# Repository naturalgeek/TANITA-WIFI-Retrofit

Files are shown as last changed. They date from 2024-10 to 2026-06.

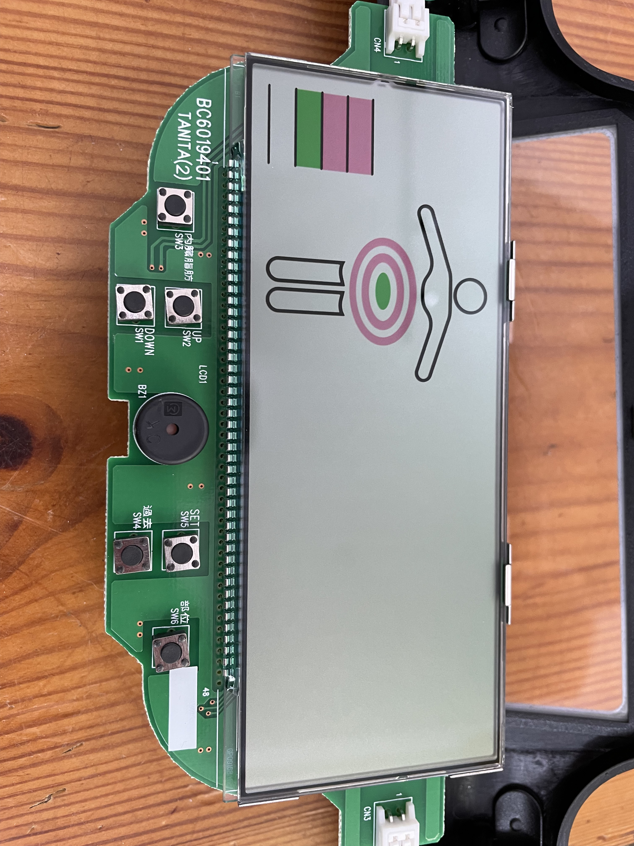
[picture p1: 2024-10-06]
photos/tanita_601_handset_pcb_bottom.jpeg

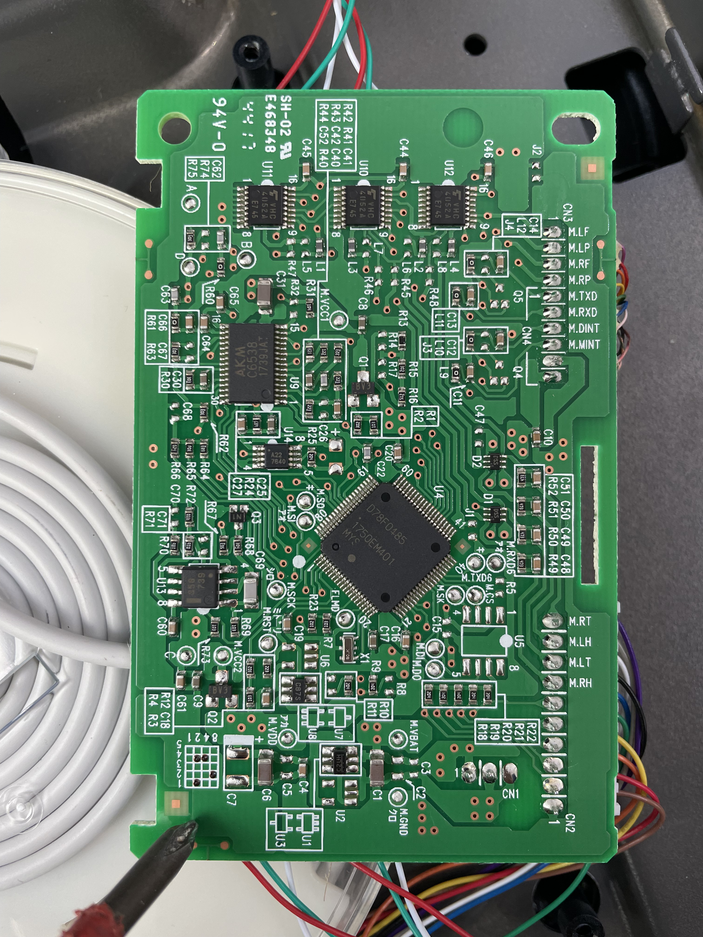
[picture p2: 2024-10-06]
photos/tanita_601_base_pcb_top.jpeg

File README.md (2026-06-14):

# TANITA-WIFI-Retrofit
I'am aiming to build a retrofit PCB to add Wifi to the Tanita 601,603 and 613 Body Scales.

# Current status
In development

# Hot it might work
basically there is a microcontroller in the handset of the scale. This microcontroller communicates to another microcontroller on a separate PCB containting the SD Cardslot via SPI. This is not SPI-SD, the communication happens in a properitary format. This SD-Card PCB can probably be replaced by something like a ESP32 which handles the communication to the mainboard and sends data to some HTTPS endpoint instead of writing it to a memory card.

# Protocol grabber

To document the proprietary protocol from real traffic (instead of guessing),
this repo includes a **passive SPI bus grabber**: an ESP32-S3 high-impedance tap
that listens to the handset ↔ SD-PCB bus while the original SD PCB stays
connected, plus a host decoder that reconstructs files and verifies checksums.

| Piece | Path |
|---|---|
| Passive sniffer firmware (ESP32-S3, dual SPI slave) | [`firmware/tanita_spi_sniffer/`](firmware/tanita_spi_sniffer/) |
| Capture decoder / protocol-doc generator | [`tools/decode_capture.py`](tools/decode_capture.py) |
| Tap schematic (KiCad 8) + wiring | [`hardware/`](hardware/) |
| Step-by-step capture workflow | [`docs/CAPTURE_WORKFLOW.md`](docs/CAPTURE_WORKFLOW.md) |
| Curated protocol spec | [`docs/PROTOCOL.md`](docs/PROTOCOL.md) |
| Auto-generated observed protocol | [`docs/PROTOCOL_OBSERVED.md`](docs/PROTOCOL_OBSERVED.md) |

Quick check that the decoder is sound (runs against the bundled capture):

```bash
python3 tools/decode_capture.py --selftest
```

> Note: the existing `firmware/tanita_spi_capture/` sketch is an **emulator**
> (it impersonates the SD card and fabricates replies) — useful for *replacing*
> the card, but the **grabber** above is the tool for *documenting* the protocol.

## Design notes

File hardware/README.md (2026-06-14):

# Hardware — Passive SPI Protocol Grabber

A high-impedance tap that lets an **ESP32-S3** listen to the SPI bus between the
TANITA handset and the original SD-Card PCB **without disturbing it**. The SD
PCB stays plugged in and the scale keeps working normally; the ESP32 only
listens and streams what it sees over USB.

## Signal map (from the SD-PCB silkscreen)

The bridge MCU on the SD PCB uses TI-style SPI names. Connector **CN1** carries
the handset link:

| CN1 signal | Meaning | = standard SPI | Direction |
|---|---|---|---|
| `SCK`  | serial clock | SCLK | handset → SD (master drives) |
| `CS` | chip select, active low | CS  | handset → SD |
| `SIMO` | Slave-In-Master-Out | **MOSI** | handset → SD |
| `SOMI` | Slave-Out-Master-In | **MISO** | SD → handset |
| `GND`  | ground | GND  | — |
| `VCC`  | ~3.3 V rail | — | **do not tap** |

> The MCU has a *second* SPI bus to the on-board SD card (silkscreen `S.SIMO`,
> `S.SOMI`, `S.SCK`). We tap **CN1 (the handset side)**, not the card side.

⚠️ **The exact wire-colour → pin order on CN1 must be confirmed on your unit**
before trusting it — see "Identify the wires" below. The grabber self-verifies
once running (it will only see valid framed traffic when SCK/CS are correct).

## Connections

| TANITA CN1 | via | ESP32-S3 GPIO | Role |
|---|-----|---|---|
| `SCK`  | R1 100 Ω | **GPIO12** | shared SPI clock (both peripherals) |
| `CS` | R2 100 Ω | **GPIO10** | shared chip select (active low) |
| `SIMO` | R3 100 Ω | **GPIO11** | MOSI → SPI2 listens here |
| `SOMI` | R4 100 Ω | **GPIO13** | MISO → SPI3 listens here |
| `GND`  | — | **GND** | **required** common ground |
| `VCC`  | — | *(leave unconnected)* | power ESP32 from USB instead |

`R1–R4` are optional ~100 Ω in-line series resistors (protection / impedance
isolation). 0 Ω / plain wire works too because the ESP32 pins are pure inputs
(`miso_io_num = -1`, so nothing is ever driven back onto the bus).

## ASCII schematic

```
 TANITA handset  <-------- ribbon -------->  SD-Card PCB (stays connected)
                         CN1 (tap here)
                         |
   CN1.SCK  o---[R1 100]---+----------------> ESP32-S3 GPIO12   (SCK,  shared)
   CN1.CS   o---[R2 100]---+----------------> ESP32-S3 GPIO10   (CS_n, shared)
   CN1.SIMO o---[R3 100]---+----------------> ESP32-S3 GPIO11   (MOSI -> SPI2)
   CN1.SOMI o---[R4 100]---+----------------> ESP32-S3 GPIO13   (MISO -> SPI3)
   CN1.GND  o-------------------------------- ESP32-S3 GND      (common)
   CN1.VCC  x  (DO NOT CONNECT)               ESP32-S3 5V <- USB
```

The two ESP32 SPI peripherals share SCK + CS and each watch one data line, so a
single CS pulse yields a byte-aligned MOSI/MISO pair. Neither peripheral drives
a pin, so the tap is invisible to the live bus.

## Breadboard wiring drawing

Physical layout (which board, which jumper) — Fritzing-breadboard style:

Breadboard wiring

Regenerate with `python3 hardware/gen_breadboard_svg.py`. Wire colours in the
drawing are **illustrative** — confirm the real CN1 wire/pin order on your unit
(see "Identify the wires" below).

## Bill of materials

| Ref | Part | Notes |
|-----|---|---|
| U1 | ESP32-S3 DevKitC (or any dual-SPI ESP32-S3) | needs SPI2 **and** SPI3 free |
| J1 | wires/clip to CN1 (JST-PH 7-pin on the SD PCB) | tap in parallel |
| R1–R4 | 100 Ω 0603/through-hole | optional but recommended |

## Schematic files

- `tanita_sniffer.kicad_sch` — KiCad 8 schematic (open with `tanita_sniffer.kicad_pro`).
- `gen_schematic.py` — regenerates the `.kicad_sch`; the netlist lives in code,
  so edit pins/nets there and re-run `python3 hardware/gen_schematic.py`.

Targets KiCad 8 (file format `20231120`). If your KiCad version refuses to open
it, the wiring tables above are the authoritative netlist.

## Identify the wires (do this first)

A dual-slave sniffer must know which CN1 wire is **SCK** and which is **CS** to
frame transactions. To confirm on your unit:

1. **GND / VCC** — power off, multimeter continuity: GND rings to the SD-card
   shield and bypass-cap ground; VCC to the cap positive.
2. **SCK** — power on, scope/logic-analyzer: a steady burst clock during a
   measurement save or on power-up.
3. **CS** — idles high, pulses low around each clock burst.
4. **SIMO vs SOMI** — capture both data lines; the one carrying the known
   command `04 12 00 E9` (handset→SD ping) is **SIMO/MOSI**; the line replying
   `04 92 00 69` is **SOMI/MISO**. If reversed, swap GPIO11/GPIO13.

A cheap 8-channel logic analyzer + `sigrok`/PulseView on all six wires for one
measurement cycle is the fastest way to lock this down before soldering.

## Safety

- TANITA logic is **3.3 V** — never feed 5 V into these pins.
- **Common the grounds.** No shared GND = garbage capture and possible damage.
- Do **not** tap VCC; powering the ESP32 from USB while also backfeeding the
  handset rail can fight the scale's regulator.

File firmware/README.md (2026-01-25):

# TANITA WiFi Retrofit - ESP32 Firmware

This firmware allows an ESP32 to replace the SD Card PCB in TANITA BC-601/603/613 body scales, enabling wireless transmission of measurement data.

## Hardware Requirements

- ESP32 development board (ESP32-WROOM-32 recommended)
- Level shifter if your ESP32 is 5V logic (the TANITA uses 3.3V)
- Connecting wires

## Wiring

Connect the ESP32 to the TANITA handset connector (the cable that normally goes to the SD Card PCB):

| TANITA Signal | ESP32 GPIO | Function |
|---|---|---|
| MOSI | GPIO23 | Data from handset to ESP32 |
| MISO | GPIO19 | Data from ESP32 to handset |
| SCLK | GPIO18 | SPI clock (from handset) |
| CS | GPIO5 | Chip select (active low) |
| VCC | 3.3V | Power |
| GND | GND | Ground |

**Important:** The TANITA handset is the SPI master; the ESP32 runs as an SPI slave.

## Sketches

### 1. tanita_spi_capture (Start here!)

Simple debug sketch for testing your wiring and capturing protocol data. This sketch:
- Captures all SPI transactions
- Logs everything to Serial (115200 baud)
- Responds to the TANITA protocol
- Displays captured measurement data

**Use this first** to verify your hardware connection works!

### 2. tanita_wifi

Full implementation with WiFi transmission. Features:
- Complete protocol implementation
- WiFi connectivity
- HTTPS POST of measurement data as JSON
- Measurement data parsing

## Building

### Using PlatformIO (Recommended)

```bash
cd firmware

# Build capture sketch
pio run -d tanita_spi_capture

# Upload capture sketch
pio run -d tanita_spi_capture --target upload

# Monitor serial output
pio device monitor -b 115200

# For the WiFi version:
pio run -d tanita_wifi
pio run -d tanita_wifi --target upload
```

### Using Arduino IDE

1. Install ESP32 board support
2. Open the `.ino` file
3. Select "ESP32 Dev Module" as board
4. Upload

## Configuration

Edit `tanita_wifi/config.h`:

```cpp
// WiFi settings
#define WIFI_SSID         "YOUR_WIFI_SSID"
#define WIFI_PASSWORD     "YOUR_WIFI_PASSWORD"

// API endpoint
#define API_ENDPOINT      "https://your-server.com/api/weight"
#define API_KEY           "your-api-key-here"

// Pin mapping (if different from defaults)
#define PIN_SPI_MOSI      23
#define PIN_SPI_MISO      19
#define PIN_SPI_SCLK      18
#define PIN_SPI_CS        5
```

## Protocol Overview

The TANITA uses a proprietary SPI protocol (NOT standard SD card SPI):

### Frame Format
```
[length] [command] [payload...] [checksum]
```

- `length`: Total frame length in bytes
- `command`: Operation code
- `payload`: Variable length data
- `checksum`: `~(sum of all other bytes) & 0xFF`

### Key Commands

| Cmd | Description |
|-----|---|
| 0x11, 0x12, 0x13 | Status/handshake |
| 0x14 | File operation init |
| 0x21 | Read file path |
| 0x22 | End transfer |
| 0x23 | Request data chunk |
| 0x24 | Write data chunk |
| 0x27 | Allocate space |
| 0x41 | Write file path |

Responses have bit 7 set: `response = command | 0x80`

### Measurement Data Format

Data is CSV with key-value pairs:
```
MO,"BC-601",DT,"01/01/2024",Ti,"08:30:00",Wk,65.5,FW,18.2,...
```

Key fields:
- `Wk`: Weight (kg)
- `FW`: Body fat (%)
- `mW`: Muscle mass (kg)
- `bW`: Bone mass (kg)
- `ww`: Body water (%)
- `rD`: BMR (kcal)
- `rA`: Metabolic age

## SPI Slave Considerations

The ESP32 runs as an SPI slave, which has timing challenges:

1. **Response Timing**: The response must be ready in the TX buffer before the master starts the next transaction
2. **Full Duplex**: SPI is simultaneous bidirectional - the first response may contain garbage
3. **DMA Required**: Use DMA for reliable data transfer

The handset appears to use separate transactions for command and response, giving us time to prepare responses.

## Troubleshooting

### No data received
- Check wiring (especially MOSI, SCLK, CS)
- Verify 3.3V power
- Check that CS pin is correctly connected

### Garbled data
- Try different SPI modes (currently using Mode 0)
- Check clock polarity with oscilloscope/logic analyzer
- Verify ground connection

### Scale shows error
- The response timing may be off
- Check checksum calculations
- Verify file content responses

### WiFi connection fails
- Check SSID and password in config.h
- Ensure router is 2.4GHz (ESP32 doesn't support 5GHz)

## Data Flow

```
[TANITA Scale] --weighs--> [Handset MCU]
                               |
                          SPI (proprietary)
                               |
                               v
                          [ESP32 Slave]
                               |
                           WiFi/HTTPS
                               |
                               v
                        [Your Server]
```

## JSON Output Format

The WiFi sketch sends data as JSON:
```json
{
  "model": "BC-601",
  "date": "01/01/2024",
  "time": "08:30:00",
  "weight": 65.5,
  "bodyFat": 18.2,
  "muscleMass": 51.5,
  "boneMass": 2.7,
  "bodyWater": 55.3,
  "bmr": 1650,
  "metabolicAge": 28,
  "physiqueRating": 5,
  "fatSegments": {
    "rightArm": 15.2,
    "leftArm": 14.8,
    "rightLeg": 18.5,
    "leftLeg": 18.2,
    "trunk": 16.8
  },
  "muscleSegments": {
    "rightArm": 3.1,
    "leftArm": 3.0,
    "rightLeg": 9.5,
    "leftLeg": 9.3,
    "trunk": 27.5
  }
}
```

## License

MIT License - See repository root for details.

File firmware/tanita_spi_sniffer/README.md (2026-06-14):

# tanita_spi_sniffer — passive SPI grabber (ESP32-S3)

Passively taps the handset ↔ SD-PCB SPI bus and streams every CS-framed
transaction over USB serial. **Listens only** — both ESP32 SPI peripherals run
as slaves with `miso_io_num = -1`, so nothing is ever driven onto the live bus.
The original SD PCB stays connected and the scale keeps working.

This is the tool to use for **documenting** the protocol. (The sibling
`tanita_spi_capture` sketch is an *emulator* that pretends to be the SD card and
fabricates replies — useful for replacement, wrong for reverse-engineering.)

## How it works

Each logical message in the TANITA protocol is its own CS pulse and is
meaningful in only one direction. To capture full duplex we run **two** SPI
slaves on the **same** SCK and CS:

| Peripheral | Listens on | Captures |
|---|---|---|
| SPI2 | `SIMO`/MOSI (GPIO11) | handset → SD |
| SPI3 | `SOMI`/MISO (GPIO13) | SD → handset |

A CS pulse ends both transactions at once, giving a byte-aligned MOSI/MISO pair.
The host decoder picks the active direction per pulse by checksum.

Pins are defined at the top of `tanita_spi_sniffer.ino` (defaults match
`hardware/README.md`). SPI mode 0 is assumed — confirm CPOL/CPHA with a scope if
you see garbage.

## Build / flash / capture

```bash
cd firmware
pio run -e sniffer -t upload          # build + flash the ESP32-S3
pio device monitor -e sniffer | tee capture.txt   # record at 921600 baud
```

Trigger traffic on the scale: power-on reads `SYSTEM.TXT` + profiles; completing
a measurement writes `DATAn.CSV`. Capture a full power-on **and** a weigh-in.

## Output format

One line per CS transaction (`#` lines are metadata):

```
<seq>\t<t_us>\t<MOSI hex bytes>\t|\t<SOMI hex bytes>
```

Example (idle line shows as 00s; decoder keeps the framed side):

```
0   1240   04 12 00 E9    |   00 00 00 00
1   1530   00 00 00 00    |   04 92 00 69
```

## Decode

```bash
python3 ../tools/decode_capture.py capture.txt              # annotated log + files
python3 ../tools/decode_capture.py capture.txt --md ../docs/PROTOCOL_OBSERVED.md
```

See `docs/CAPTURE_WORKFLOW.md` for the full procedure.

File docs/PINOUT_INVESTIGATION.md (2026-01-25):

# Connector Pinout Investigation Guide

## The Connector

Based on the photos, the SD Card PCB has a 6-7 pin connector with colored wires going to the handset. You'll need to identify which wire corresponds to which SPI signal.

## Expected Signals

For SPI communication, we need:
| Signal | Description |
|---|---|
| VCC | 3.3V Power (likely red or orange wire) |
| GND | Ground |
| MOSI | Master Out Slave In (data TO the SD PCB) |
| MISO | Master In Slave Out (data FROM the SD PCB) |
| SCLK | SPI Clock |
| CS | Chip Select (active low) |

## Investigation Methods

### Method 1: Visual Inspection

From the PCB top photo, I can see "VCC" labeled near the connector. Trace other signals by following PCB traces to:
- The main microcontroller
- The SD card slot pins (standard SD card pinout is documented)

### Method 2: Multimeter Continuity Test

With the board powered OFF:
1. Set multimeter to continuity mode
2. Find GND by testing for continuity to the SD card slot's GND pins
3. Find VCC by testing for continuity to bypass capacitors' positive side
4. SPI signals will go to the microcontroller

### Method 3: Logic Analyzer / Oscilloscope

With the board connected to the handset (powered on):
1. Connect logic analyzer probes to each wire
2. Trigger a measurement on the scale
3. Identify signals by their characteristics:
   - **SCLK**: Regular clock pulses
   - **MOSI**: Data changing on clock edges (commands from handset)
   - **MISO**: Data changing on clock edges (responses from SD PCB)
   - **CS**: Goes low during transactions

### Method 4: Compare with SD Card Pinout

Standard SD card SPI pinout (looking at card from front, contacts up):
```
Pin 1: CS (Chip Select)
Pin 2: MOSI (Data In)
Pin 3: GND
Pin 4: VCC (3.3V)
Pin 5: SCLK (Clock)
Pin 6: GND
Pin 7: MISO (Data Out)
```

However, remember the TANITA uses a **proprietary protocol**, not standard SD SPI. The microcontroller on the SD PCB translates between the proprietary protocol and actual SD card access.

## Wire Color Observations

From the photos, the visible wire colors are approximately:
- Red/Orange
- Yellow
- Green
- Blue
- Purple/Pink
- (possibly more)

Common conventions (may not apply):
- Red = VCC
- Black = GND
- Other colors = signals

## Recommended Approach

1. **Identify VCC and GND first** using multimeter
2. **Use logic analyzer** to capture actual SPI communication
3. Compare captured data with the protocol documentation
4. Once you identify MOSI (data from handset), you should see the known command sequences

## Safety Notes

- The TANITA operates at 3.3V - do NOT connect 5V signals
- Always verify power connections before connecting your ESP32
- Start with the capture sketch to verify wiring before using the full firmware

## ESP32 Default Pin Mapping

Once you identify the signals, connect them to these ESP32 pins:

| Signal | ESP32 GPIO | Notes |
|---|---|---|
| VCC | 3.3V pin | Power from TANITA or external |
| GND | GND | Common ground |
| MOSI | GPIO23 | Can be changed in config.h |
| MISO | GPIO19 | Can be changed in config.h |
| SCLK | GPIO18 | Can be changed in config.h |
| CS | GPIO5 | Can be changed in config.h |

## Example Logic Analyzer Capture

When you capture SPI data, you should see patterns like:

**Ping-Pong Handshake:**
```
MOSI: 04 12 00 E9
MISO: 04 92 00 69
```

**File Path Request:**
```
MOSI: 23 21 54 41 4E 49 54 41 2F ...  (TANITA/...)
```

If your MOSI/MISO are swapped, swap your connections!

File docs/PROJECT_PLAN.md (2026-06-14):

# TANITA WiFi Retrofit - Project Plan

## Project Overview

**Goal:** Replace the SD Card PCB in TANITA BC-601/603/613 body scales with an ESP32 to send weight/body composition data via WiFi instead of storing to SD card.

**Repository:** https://github.com/naturalgeek/TANITA-WIFI-Retrofit

**Two tools, two jobs** (don't confuse them):
- **Grabber** (`firmware/tanita_spi_sniffer`) — passively taps the live bus to *document* the protocol from real traffic. The original SD PCB stays connected.
- **Emulator** (`firmware/tanita_spi_capture`, `firmware/tanita_wifi`) — *impersonates* the SD card and answers the handset. This is what eventually *replaces* the card and adds WiFi.

---

## Current Status (June 2026)

### Completed ✅

| Task | Status | Notes |
|---|---|---|
| Protocol reverse engineering | ✅ Done | SPI captures analyzed, frame format decoded |
| Protocol documentation | ✅ Done | `docs/PROTOCOL.md` — curated reference |
| Checksum algorithm | ✅ **Verified** | `~(sum of bytes) & 0xFF`; decoder self-test = 0 failures across 78 real frames |
| Command/response mapping | ✅ Done | All observed commands documented |
| Data format parsing | ✅ Done | CSV key-value format understood |
| **Passive SPI grabber firmware** | ✅ Done | `firmware/tanita_spi_sniffer/` — ESP32-S3 dual-SPI-slave, listens only |
| **Capture decoder / doc generator** | ✅ Done | `tools/decode_capture.py` — validates checksums, reconstructs files, emits `PROTOCOL_OBSERVED.md`; ships `--selftest` |
| **Observed-protocol doc (auto-gen)** | ✅ Done | `docs/PROTOCOL_OBSERVED.md` generated from the bundled capture |
| **Capture workflow** | ✅ Done | `docs/CAPTURE_WORKFLOW.md` — tap → flash → capture → decode |
| **KiCad schematic (tap)** | ✅ Done | `hardware/tanita_sniffer.kicad_sch` (+ generator) |
| **Breadboard wiring drawing** | ✅ Done | `hardware/tanita_sniffer_breadboard.svg` (+ generator) |
| Signal naming confirmed (silkscreen) | ✅ Done | `SIMO`=MOSI, `SOMI`=MISO, `SCK`, `CS`, `GND`, `VCC`; 2nd (SD-side) bus identified |
| ESP32 firmware (emulator) | ✅ Done | `firmware/tanita_spi_capture/` |
| ESP32 firmware (WiFi) | ✅ Done | `firmware/tanita_wifi/` |
| Wiring guide | ✅ Done | `docs/WIRING_GUIDE.md` with ASCII diagrams |
| Pinout investigation guide | ✅ Done | `docs/PINOUT_INVESTIGATION.md` |
| PlatformIO config | ✅ Done | `firmware/platformio.ini` — per-env source filters (`sniffer`/`capture`/`wifi`) |

### In Progress / Pending hardware 🔄

| Task | Status | Blocker |
|---|---|---|
| Confirm exact CN1 wire→pin order | 🔄 Pending | Multimeter + logic analyzer on the physical unit |
| Compile-test all firmware | 🔄 Pending | No ESP toolchain in the dev env yet (`pio run`) |
| Open KiCad schematic in KiCad | 🔄 Pending | Targets format `20231120` (KiCad 8); not yet opened |
| Run the grabber on real hardware | 🔄 Pending | Requires wired tap + a measurement cycle |
| Real-world testing | 🔄 Pending | Requires hardware setup |

### Not Started ⏳

| Task | Priority | Complexity |
|---|---|---|
| Verify SPI mode (CPOL/CPHA) on scope | High | Low |
| Capture real power-on + weigh-in with grabber | High | Low |
| Reconcile `PROTOCOL.md` vs captured `PROTOCOL_OBSERVED.md` | High | Low |
| Validate emulator against the live scale | High | Medium |
| WiFi endpoint integration | Medium | Low |
| Power consumption optimization | Low | Medium |
| Custom PCB design | Low | High |
| 3D printed enclosure | Low | Medium |

---

## Milestones

### Milestone 1: Bench bring-up & wire identification 🎯
**Target:** Know exactly which CN1 wire is which, and the bus's electrical params.

- [ ] Identify GND/VCC with multimeter; SCK/CS/SIMO/SOMI with logic analyzer
- [ ] Document wire-colour → signal mapping for your unit
- [ ] Measure clock frequency and confirm 3.3 V levels
- [ ] Confirm SPI mode (CPOL/CPHA) on a scope

### Milestone 2: Passive protocol grab & documentation 🎯  *(recommended first — non-invasive)*
**Target:** Ground-truth protocol docs generated from real traffic, SD PCB untouched.

- [ ] `pio run -e sniffer -t upload` (compile-test first)
- [ ] Wire the high-impedance tap (see `hardware/` schematic + breadboard SVG)
- [ ] Capture a full **power-on** (reads SYSTEM.TXT, PROF*.CSV)
- [ ] Capture a full **weigh-in** (writes DATA*.CSV)
- [ ] `decode_capture.py capture.txt --md docs/PROTOCOL_OBSERVED.md` → 0 checksum failures
- [ ] Reconcile `docs/PROTOCOL.md` with the captured `PROTOCOL_OBSERVED.md` (capture wins)

### Milestone 3: Emulator validation 🎯
**Target:** ESP32 impersonates the SD card; the scale completes a measurement.

- [ ] `pio run -e capture -t upload`
- [ ] Verify ping-pong handshake (0x12/0x92, 0x13/0x93, 0x11/0x91)
- [ ] Verify file-read responses (SYSTEM.TXT, PROF1.CSV)
- [ ] Verify file-write capture (DATA1.CSV)
- [ ] Scale completes measurement without errors

### Milestone 4: WiFi Integration 🎯
**Target:** Measurement data sent to a server.

- [ ] Configure WiFi credentials (`config.h`)
- [ ] Stand up an HTTPS endpoint and verify JSON payload
- [ ] Test data transmission with real measurements
- [ ] Handle connection failures gracefully

### Milestone 5: Production Ready 🎯
**Target:** Reliable, permanent installation.

- [ ] Long-term stability testing
- [ ] Power from TANITA (not USB)
- [ ] Design custom adapter PCB
- [ ] Create 3D printed enclosure
- [ ] Document final installation process

---

## Task Backlog (Linear Import Format)

### Epic: Hardware Setup

```
[HIGH] Identify TANITA connector pinout      [partially done]
- Signal NAMES confirmed from SD-PCB silkscreen (SIMO/SOMI/SCK/CS/GND/VCC)
- Still need: wire-colour -> pin-order mapping on the physical CN1
- Use multimeter (GND/VCC) + logic analyzer (SPI lines)
Labels: hardware, blocking
Estimate: 1h

[HIGH] Wire the passive tap
- Tap SCK/CS/SIMO/SOMI + common GND in parallel with the SD PCB
- Do NOT connect handset VCC; power ESP32 from USB
- See hardware/ schematic + breadboard SVG
Labels: hardware
Estimate: 1h
Depends: Identify connector pinout

[MEDIUM] Verify SPI electrical characteristics
- Measure clock frequency, confirm 3.3V levels, check CPOL/CPHA
Labels: hardware, investigation
Estimate: 1h
```

### Epic: Toolchain / CI

```
[HIGH] Compile-test all three sketches
- pio run -e sniffer / -e capture / -e wifi
- Firmware was authored without a local ESP toolchain; never built yet
Labels: firmware, blocking
Estimate: 1h

[LOW] Open hardware/tanita_sniffer.kicad_sch in KiCad 8
- Confirm it loads + ERC clean; regenerate via gen_schematic.py if needed
Labels: hardware, verification
Estimate: 0.5h
```

### Epic: Protocol Grab & Documentation

```
[HIGH] Capture real traffic with the grabber
- Flash tanita_spi_sniffer, record power-on + a full weigh-in at 921600 baud
- pio device monitor -e sniffer | tee capture.txt
Labels: firmware, protocol, testing
Depends: Wire the passive tap
Estimate: 1h

[HIGH] Decode + regenerate observed protocol doc
- decode_capture.py capture.txt --md docs/PROTOCOL_OBSERVED.md
- Expect 0 checksum failures; reconstructed files match declared sizes
Labels: tooling, protocol
Estimate: 0.5h

[MEDIUM] Reconcile curated vs observed protocol
- Diff PROTOCOL.md against PROTOCOL_OBSERVED.md; capture is source of truth
- Commit the capture under protocol/ as evidence
Labels: documentation, protocol
Estimate: 1h
```

### Epic: Emulator Validation

```
[HIGH] Validate handshake + file read/write against the live scale
- Upload tanita_spi_capture; scale must complete a measurement
- Verify handshake, SYSTEM.TXT/PROF1.CSV reads, DATA1.CSV write
Labels: firmware, protocol, testing
Depends: Capture real traffic with the grabber
Estimate: 3h

[MEDIUM] Handle edge cases
- Multiple profiles (PROF2-4), guest mode, error recovery
Labels: firmware, protocol
Estimate: 3h
```

### Epic: WiFi Integration

```
[MEDIUM] Configure WiFi connection
- Set credentials in config.h, test stability + reconnection
Labels: firmware, wifi
Estimate: 1h

[MEDIUM] Set up test endpoint
- Simple HTTPS server, accept JSON POST, log received data
Labels: backend, testing
Estimate: 2h

[MEDIUM] Test data transmission
- Verify JSON format + all measurement fields with real measurements
Labels: firmware, testing
Estimate: 2h

[LOW] Add data buffering
- Store measurements offline, retry failed sends, SPIFFS persistence
Labels: firmware, enhancement
Estimate: 4h
```

### Epic: Production Hardening

```
[LOW] Optimize power consumption
- Measure current draw, sleep modes, battery impact
Labels: firmware, optimization
Estimate: 4h

[LOW] Design adapter PCB
- Schematic -> layout -> prototype (start from hardware/ KiCad files)
Labels: hardware, pcb
Estimate: 8h

[LOW] Create enclosure
- Measure available space, design 3D model, print + test fit
Labels: hardware, mechanical
Estimate: 4h

[LOW] Write installation guide
- Step-by-step instructions, photos, troubleshooting
Labels: documentation
Estimate: 2h
```

---

## Risk Register

| Risk | Probability | Impact | Mitigation |
|---|---|---|---|
| SPI timing too fast for ESP32 slave | Medium | High | DMA + queued transactions (`QUEUE_DEPTH`); grabber confirms achievable rate |
| Wrong SPI mode → garbage capture | Medium | Medium | Confirm CPOL/CPHA on scope before trusting captures |
| Grabber misses back-to-back transactions | Low | Medium | Raise `QUEUE_DEPTH`; decoder flags checksum gaps |
| Protocol has undocumented commands | Low | Medium | Grabber + decoder surface unknown opcodes; capture more scenarios |
| Firmware untested on hardware (not yet built) | High | Medium | Compile-test, then bench-validate on a real unit |
| TANITA power insufficient for ESP32 | Medium | Medium | Use external/USB power |
| Different TANITA models differ | Low | High | Re-grab per model; protocol is data-driven |

---

## Technical Debt

1. **Firmware never compiled or hardware-tested** — authored without an ESP toolchain; build + bench-validate before trusting.
2. **KiCad schematic not opened in KiCad** — generated to format `20231120`; verify load + ERC.
3. **Breadboard wire colours are illustrative** — real CN1 colour order must be confirmed per unit.
4. **SPI Mode hardcoded** — Mode 0 assumed in both sniffer and emulator; may need configuration.
5. **No persistent storage (WiFi path)** — measurements lost if WiFi fails.
6. **Hardcoded profile data in emulator** — should read from the actual scale config.
7. **No OTA updates** — requires USB for firmware updates.

---

## Resources

- Curated protocol spec: `docs/PROTOCOL.md`
- Auto-generated observed protocol: `docs/PROTOCOL_OBSERVED.md`
- Capture workflow: `docs/CAPTURE_WORKFLOW.md`
- Wiring guide: `docs/WIRING_GUIDE.md`
- Pinout investigation: `docs/PINOUT_INVESTIGATION.md`
- Hardware (schematic + breadboard + BOM): `hardware/`
- Capture decoder: `tools/decode_capture.py` (`--selftest`)
- Firmware READMEs: `firmware/README.md`, `firmware/tanita_spi_sniffer/README.md`
- Hardware photos: `photos/`

---

## Timeline Estimate

| Phase | Duration | Dependencies |
|---|---|---|
| Bench bring-up + wire ID | 0.5-1 day | Logic analyzer, multimeter |
| Passive grab + doc reconciliation | 0.5-1 day | Wired tap, compiled sniffer |
| Emulator validation | 2-3 days | Captured protocol, working hardware |
| WiFi integration | 1 day | Validated emulator |
| Production hardening | 1-2 weeks | Optional |

**Minimum viable prototype:** ~1 week from hardware setup start.

---

_Last updated: 2026-06-14 — reflects the passive grabber + decoder + hardware tooling merged in PR #2._

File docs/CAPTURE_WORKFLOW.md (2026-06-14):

# Capture Workflow — from bus tap to accurate protocol docs

End-to-end recipe for grabbing the TANITA SPI protocol and turning the raw
capture into verified documentation.

```
 ┌────────────┐   ribbon    ┌────────────┐
 │  handset   │◄───────────►│  SD-Card   │   (untouched, still works)
 │ (SPI master)│   CN1 tap  │   PCB      │
 └─────┬──────┘             └────────────┘
       │ high-Z parallel tap (SCK,CS,SIMO,SOMI,GND)
       ▼
 ┌────────────┐   USB 921600   ┌──────────┐   decode_capture.py   ┌────────────────────┐
 │  ESP32-S3  │───────────────►│  host PC │──────────────────────►│ PROTOCOL_OBSERVED.md│
 │ dual SPI   │  raw frames    │ capture  │  annotate + verify    │ + reconstructed     │
 │  slave     │                │  .txt    │  checksum + files     │   virtual files     │
 └────────────┘                └──────────┘                       └────────────────────┘
```

## 1. Wire the tap

Follow `hardware/README.md`. Confirm **SCK** and **CS** first (the sniffer can't
frame without them). A logic analyzer on all six CN1 wires for one measurement
cycle is the quickest way to identify them. **Common the grounds.**

## 2. Flash the grabber

```bash
cd firmware
pio run -e sniffer -t upload
```

## 3. Record real traffic

```bash
pio device monitor -e sniffer | tee capture.txt
```

Exercise every protocol path you want documented:

- **Power-on** → reads `SYSTEM.TXT`, `PROF*.CSV` (status pings + reads).
- **Complete a weigh-in** → writes `DATA*.CSV` (allocate + write chunks).
- **Add/edit a user profile** → profile writes.

Let it run through a full cycle, then stop the monitor (Ctrl-C).

## 4. Decode and verify

```bash
# annotated transaction log + reconstructed files to stdout
python3 tools/decode_capture.py capture.txt

# regenerate the observed-protocol document
python3 tools/decode_capture.py capture.txt --md docs/PROTOCOL_OBSERVED.md
```

The decoder:

- validates every frame's length + checksum (flags `BAD_CHECKSUM`),
- labels each opcode (`OPEN_READ`, `READ_DATA`, `WRITE_CHUNK`, …),
- reconstructs the virtual files and compares declared vs actual size,
- emits a Markdown report built **only** from observed frames.

A clean capture has **zero checksum failures** and reconstructs files whose byte
length matches the `FILE_INFO` declared size. If you see failures, suspect wrong
SPI mode, a swapped SIMO/SOMI, or missed transactions (raise `QUEUE_DEPTH`).

## 5. Validate the decoder itself

The decoder ships with a self-test against the known-good bundled dump:

```bash
python3 tools/decode_capture.py --selftest
```

Expected: 78 frames, 0 checksum failures, `SYSTEM.TXT`/`PROF1.CSV` reconstructed
byte-exact — proves the frame parser before you trust it on new captures.

## 6. Promote to canonical docs

`docs/PROTOCOL.md` is the curated, hand-maintained spec.
`docs/PROTOCOL_OBSERVED.md` is machine-generated ground truth from a capture.
When they disagree, **the capture wins** — update `PROTOCOL.md` to match, and
keep the capture that proves it under `protocol/`.

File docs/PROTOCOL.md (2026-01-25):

# TANITA BC-601/603/613 SPI Protocol Documentation

This document describes the proprietary SPI protocol used between the TANITA handset and the SD Card PCB.

## Overview

The handset communicates with the SD Card PCB using a custom SPI protocol (NOT standard SD card SPI). The ESP32 must act as an **SPI Slave** to receive commands from the handset (master).

## Physical Layer

- **Interface:** SPI (Serial Peripheral Interface)
- **Voltage:** 3.3V
- **Mode:** SPI Mode 0 (CPOL=0, CPHA=0) - to be confirmed
- **Byte Order:** MSB first
- **Clock Speed:** ~1-4 MHz (estimated)

## Frame Structure

All frames end with a checksum byte calculated as:
```
checksum = ~(sum of all other bytes) & 0xFF
```

Example:
- Frame: `04 12 00 E9`
- Sum: 0x04 + 0x12 + 0x00 = 0x16
- Checksum: ~0x16 & 0xFF = 0xE9 ✓

## Command Types

### 1. Status/Handshake Commands (Ping-Pong)

These occur at startup and before each file operation.

| MOSI (Command) | MISO (Response) | Description |
|---|---|---|
| `04 12 00 E9` | `04 92 00 69` | Status check 1 |
| `04 13 00 E8` | `04 93 00 68` | Status check 2 |
| `04 11 00 EA` | `04 91 01 69` | Ready check (response has 01 = ready) |

**Pattern:** Response command byte = Request command byte | 0x80

### 2. File Init Command

Before any file operation:
```
MOSI: 07 14 21 3A [3 bytes param] [checksum]
MISO: 04 94 00 67
```

### 3. File Read Operations

#### Open File for Read
```
MOSI: [len] 21 [filepath ASCII] [checksum]
      len = 0x22 or 0x23 depending on path length

MISO: 0D A1 00 00 00 00 00 00 [filesize 4 bytes LE] [checksum]
```

#### Read Data Chunk
```
MOSI: 04 23 [chunk_size] [checksum]
      chunk_size is typically 0x20 (32 bytes)

MISO: [len] A3 00 00 [offset 4 bytes LE] [data bytes] [checksum]
```

#### End Read
```
MOSI: 04 22 00 D9
MISO: 09 A2 00 00 [final_offset 4 bytes LE] [checksum]
```

### 4. File Write Operations

#### Open File for Write
```
MOSI: [len] 21 [filepath ASCII] [checksum]
MISO: 0D A1 00 00 00 00 00 00 [current_size 4 bytes LE] [checksum]
```

#### Allocate Space
```
MOSI: 07 27 [address 2 bytes] 00 00 [checksum]
MISO: 09 A7 00 00 [address 4 bytes LE] [checksum]
```

#### Begin Write
```
MOSI: [len] 41 [filepath ASCII] [extra bytes] [checksum]
MISO: 04 C1 00 3A
```

#### Write Data Chunk
```
MOSI: [len] 24 [data bytes] [checksum]
      len = 0x23 for 32-byte chunks, 0x19 for smaller final chunk

MISO: 09 A4 00 00 [next_address 4 bytes LE] [checksum]
```

#### End Write
```
MOSI: 04 22 00 D9
```

## Virtual Filesystem

The protocol simulates an SD card filesystem:

```
TANITA/
└── GRAPHV1/
    ├── SYSTEM/
    │   ├── SYSTEM.TXT    (system config)
    │   └── PROF1.CSV     (user profile 1)
    │   └── PROF2.CSV     (user profile 2, etc.)
    └── DATA/
        └── DATA1.CSV     (measurement data for profile 1)
```

### SYSTEM.TXT Format
```
SD,TANITA,GRAPHV1
Do not delete, modify, nor remove this system file by yourself!
```

### PROFn.CSV Format (Profile Configuration)
```
{0,16,~1,2,~3,4,MO,"BC-601",DB,"31/08/1985",Bt,0,GE,1,Hm,173.0,AL,2,CS,F4
```

Fields:
- `MO` - Model name
- `DB` - Date of birth (DD/MM/YYYY)
- `Bt` - Body type (0=standard, 1=athlete)
- `GE` - Gender (1=male, 2=female)
- `Hm` - Height in cm
- `AL` - Activity level
- `CS` - Checksum (hex)

### DATAn.CSV Format (Measurement Data)
```
{0,16,~0,2,~1,2,~2,3,~3,4,MO,"BC-601",DT,"01/01/2009",Ti,"08:38:37",
Bt,0,GE,1,AG,23,Hm,173.0,AL,2,Wk,61.9,MI,20.7,FW,12.4,Fr,11.9,
Fl,12.9,FR,8.8,FL,10.5,FT,14.2,mW,51.5,mr,3.0,ml,2.9,mR,9.5,mL,9.0,
mT,27.1,bW,2.7,IF,1,rD,2848,rA,12,ww,63.3,CS,6E
```

#### Measurement Fields

| Field | Description | Unit |
|---|---|---|
| MO | Model | string |
| DT | Date | DD/MM/YYYY |
| Ti | Time | HH:MM:SS |
| Bt | Body type | 0=standard, 1=athlete |
| GE | Gender | 1=male, 2=female |
| AG | Age | years |
| Hm | Height | cm |
| AL | Activity level | 1-5 |
| Wk | Weight | kg |
| MI | Muscle/BMI indicator | % |
| FW | Fat - Whole body | % |
| Fr | Fat - Right arm | % |
| Fl | Fat - Left arm | % |
| FR | Fat - Right leg | % |
| FL | Fat - Left leg | % |
| FT | Fat - Trunk | % |
| mW | Muscle - Whole body | kg |
| mr | Muscle - Right arm | kg |
| ml | Muscle - Left arm | kg |
| mR | Muscle - Right leg | kg |
| mL | Muscle - Left leg | kg |
| mT | Muscle - Trunk | kg |
| bW | Bone mass | kg |
| IF | Physique rating | 1-9 |
| rD | BMR (daily) | kcal |
| rA | Metabolic age | years |
| ww | Body water | % |
| CS | Checksum | hex |

## Communication Sequence

### Startup (Read Profile)
```
1. Ping-Pong handshake (3 exchanges)
2. File init command
3. Open SYSTEM.TXT, read contents
4. Ping-Pong handshake (2 exchanges)
5. File init command
6. Open PROF1.CSV, read contents
```

### After Measurement (Write Data)
```
1. Ping-Pong handshake (multiple exchanges)
2. File init command
3. Open DATA1.CSV for write
4. Allocate space for new data
5. Write file path confirmation
6. Write data in 32-byte chunks
7. End write transaction
```

## Implementation Notes

1. **ESP32 as SPI Slave:** The ESP32 must respond to commands from the handset within the SPI clock cycle. Use hardware SPI slave mode with DMA if possible.

2. **Timing:** Responses must be ready before the next SPI transaction. Pre-calculate expected responses.

3. **Checksum:** Always validate incoming checksums and calculate correct outgoing checksums.

4. **File Simulation:** The ESP32 must simulate the virtual filesystem, providing appropriate responses for file reads and accepting writes.

5. **Data Capture:** The goal is to capture the measurement data from write operations and send it via WiFi instead of storing to SD card.

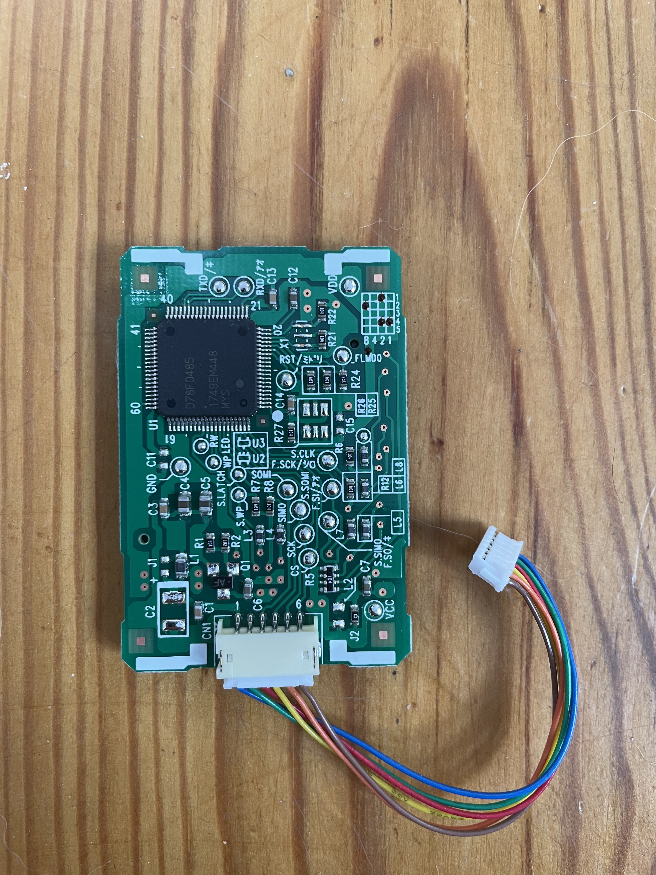
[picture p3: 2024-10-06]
photos/tanita_601_sd_pcb_top.jpeg

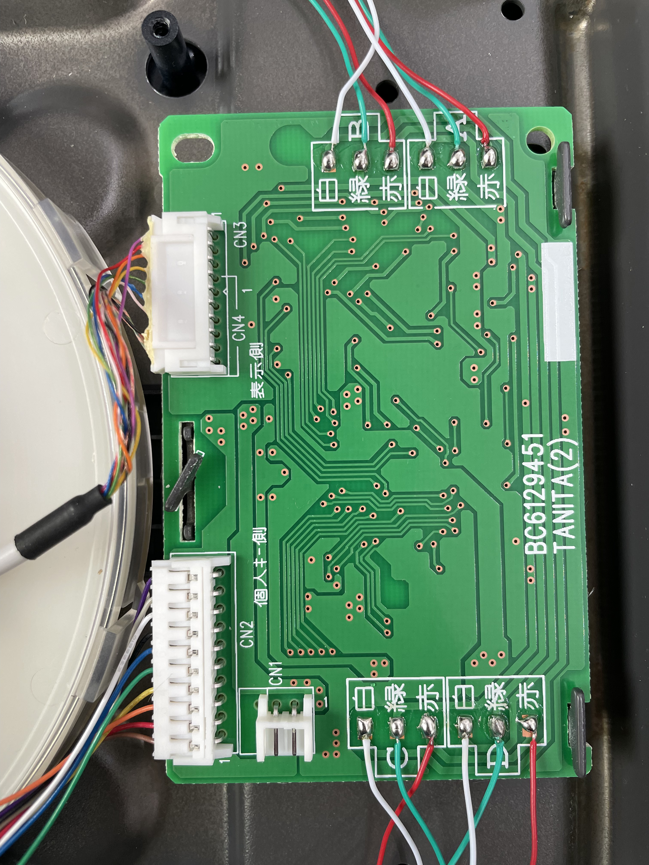
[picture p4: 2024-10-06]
photos/tanita_601_base_pcb_bottom.jpeg

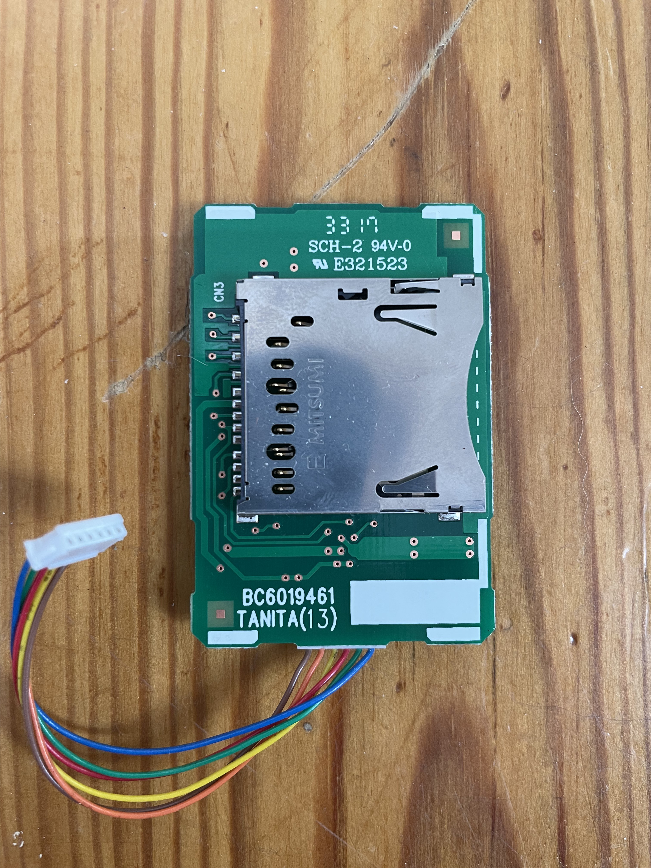
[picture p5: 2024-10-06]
photos/tanita_601_sd_pcb_bottom.jpeg

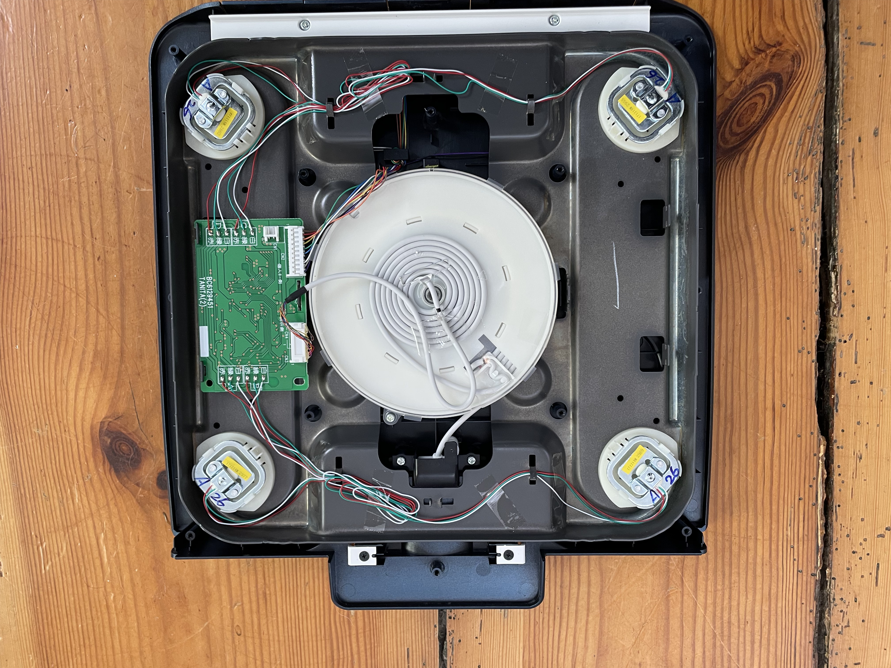
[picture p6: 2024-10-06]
photos/tanita_601_base.jpeg

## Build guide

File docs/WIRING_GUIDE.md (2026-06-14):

# TANITA WiFi Retrofit - Wiring Guide

## Overview

This guide explains how to connect an ESP32 development board to replace the SD Card PCB in your TANITA BC-601/603/613 body scale.

```
┌─────────────────┐                      ┌─────────────────┐
│                 │    6-wire cable      │                 │
│  TANITA Scale   │◄────────────────────►│   ESP32 Board   │
│   (Handset)     │   (SPI + Power)      │                 │
│                 │                      │                 │
└─────────────────┘                      └─────────────────┘
        │                                        │
        │                                        │
   [Measurements]                         [WiFi to Server]
```

---

## Required Components

| Item | Quantity | Notes |
|---|---|---|
| ESP32 Dev Board | 1 | ESP32-WROOM-32 or similar |
| Dupont Wires (Female-Female) | 6 | For connecting to existing cable |
| Breadboard | 1 | Optional, for prototyping |
| USB Cable | 1 | For programming/power |

---

## The TANITA Connector Cable

The SD Card PCB connects to the handset via a 6-wire cable with a white JST-style connector.

### Cable Wire Colors (from photos)

```
┌───────────────────────────────────────┐
│         TANITA Cable Connector        │
│                                       │
│   ┌───┬───┬───┬───┬───┬───┐          │
│   │ 1 │ 2 │ 3 │ 4 │ 5 │ 6 │          │
│   └───┴───┴───┴───┴───┴───┘          │
│     │   │   │   │   │   │            │
│     │   │   │   │   │   └─ Wire 6    │
│     │   │   │   │   └───── Wire 5    │
│     │   │   │   └───────── Wire 4    │
│     │   │   └───────────── Wire 3    │
│     │   └───────────────── Wire 2    │
│     └───────────────────── Wire 1    │
│                                       │
│   Colors observed (verify yours!):    │
│   Orange, Yellow, Green, Blue,        │
│   Purple/Pink, Red                    │
└───────────────────────────────────────┘
```

### Identifying the Signals

**YOU MUST VERIFY THESE WITH A MULTIMETER/LOGIC ANALYZER!**

Typical SPI signal assignment (needs verification):

```
┌─────────┬──────────┬─────────────────────────────┐
│ Pin #   │ Signal   │ How to Identify             │
├─────────┼──────────┼─────────────────────────────┤
│ 1       │ VCC      │ 3.3V when powered on        │
│ 2       │ GND      │ Continuity to battery (-)   │
│ 3       │ MOSI     │ Data pulses FROM handset    │
│ 4       │ MISO     │ Data pulses TO handset      │
│ 5       │ SCLK     │ Regular clock signal        │
│ 6       │ CS       │ Goes LOW during transfers   │
└─────────┴──────────┴─────────────────────────────┘
```

---

## ESP32 Pinout Reference

### ESP32-WROOM-32 DevKit V1 (30-pin)

```
                    ┌───────────────────┐
                    │       USB         │
                    │      ┌───┐        │
              EN ──┤1    ─┤   ├─    30├── D23 (MOSI) ◄── TANITA MOSI
             VP  ──┤2     │   │     29├── D22
             VN  ──┤3     │ESP│     28├── TX0
            D34  ──┤4     │32 │     27├── RX0
            D35  ──┤5     │   │     26├── D21
            D32  ──┤6     │   │     25├── D19 (MISO) ──► TANITA MISO
            D33  ──┤7     └───┘     24├── D18 (SCLK) ◄── TANITA SCLK
            D25  ──┤8               23├── D5  (CS)   ◄── TANITA CS
            D26  ──┤9               22├── D17
            D27  ──┤10              21├── D16
            D14  ──┤11              20├── D4
            D12  ──┤12              19├── D2  (LED)
            D13  ──┤13              18├── D15
            GND  ──┤14  ◄── TANITA  17├── GND
            VIN  ──┤15      GND     16├── 3V3 ◄── TANITA VCC (if needed)
                    └───────────────────┘
```

### ESP32-WROOM-32 DevKit (38-pin)

```
                    ┌─────────────────────┐
                    │        USB          │
                    │       ┌───┐         │
            3V3  ──┤1     ─┤   ├─     38├── GND
             EN  ──┤2      │   │      37├── D23 (MOSI) ◄── TANITA MOSI
            VP   ──┤3      │ESP│      36├── D22
            VN   ──┤4      │32 │      35├── TX0
            D34  ──┤5      │   │      34├── RX0
            D35  ──┤6      │   │      33├── D21
            D32  ──┤7      └───┘      32├── D19 (MISO) ──► TANITA MISO
            D33  ──┤8                 31├── D18 (SCLK) ◄── TANITA SCLK
            D25  ──┤9                 30├── D5  (CS)   ◄── TANITA CS
            D26  ──┤10                29├── D17
            D27  ──┤11                28├── D16
            D14  ──┤12                27├── D4
            D12  ──┤13                26├── D2  (LED)
            GND  ──┤14                25├── D15
            D13  ──┤15                24├── GND
            D9   ──┤16                23├── D3
            D10  ──┤17                22├── D1
            D11  ──┤18                21├── CMD
            VIN  ──┤19                20├── CLK
                    └─────────────────────┘
```

---

## Wiring Diagram

### Connection Overview

```
┌────────────────────────────────────────────────────────────────────┐
│                                                                    │
│   TANITA SD PCB Connector              ESP32 DevKit                │
│   (Cable from Handset)                                             │
│                                                                    │
│   ┌─────────────┐                     ┌─────────────────┐          │
│   │             │                     │                 │          │
│   │  Pin 1: VCC ├────────────────────►│ 3V3 (optional)  │          │
│   │             │    (red wire?)      │                 │          │
│   │             │                     │                 │          │
│   │  Pin 2: GND ├────────────────────►│ GND             │          │
│   │             │    (black wire?)    │                 │          │
│   │             │                     │                 │          │
│   │  Pin 3: MOSI├────────────────────►│ GPIO23          │          │
│   │             │    (data to ESP)    │                 │          │
│   │             │                     │                 │          │
│   │  Pin 4: MISO│◄────────────────────┤ GPIO19          │          │
│   │             │    (data from ESP)  │                 │          │
│   │             │                     │                 │          │
│   │  Pin 5: SCLK├────────────────────►│ GPIO18          │          │
│   │             │    (clock)          │                 │          │
│   │             │                     │                 │          │
│   │  Pin 6: CS  ├────────────────────►│ GPIO5           │          │
│   │             │    (chip select)    │                 │          │
│   │             │                     │                 │          │
│   └─────────────┘                     └─────────────────┘          │
│                                                                    │
└────────────────────────────────────────────────────────────────────┘

Signal Direction:
    ────► = Signal flows TO ESP32 (inputs)
    ◄──── = Signal flows FROM ESP32 (outputs)
```

### Breadboard Layout

```
        ┌──────────────────────────────────────────────────────────┐
        │                      BREADBOARD                          │
        │                                                          │
        │   1  5    10   15   20   25   30   35   40   45   50    │
        │   ┌──┬──┬──┬──┬──┬──┬──┬──┬──┬──┬──┬──┬──┬──┬──┬──┐    │
        │ A │  │  │  │  │  │  │  │  │  │  │  │  │  │  │  │  │    │
        │   ├──┼──┼──┼──┼──┼──┼──┼──┼──┼──┼──┼──┼──┼──┼──┼──┤    │
        │ B │  │  │  │  │  │  │  │  │  │  │  │  │  │  │  │  │    │
        │   ├──┼──┼──┼──┼──┼──┼──┼──┼──┼──┼──┼──┼──┼──┼──┼──┤    │
        │ C │▓▓│▓▓│▓▓│▓▓│▓▓│▓▓│▓▓│▓▓│▓▓│▓▓│▓▓│▓▓│▓▓│▓▓│▓▓│  │    │
        │   ├──┼──┴──┴──┴──┴──┴──┴──┴──┴──┴──┴──┴──┴──┼──┼──┤    │
        │ D │  │░░░░░░░░░░░ ESP32 ░░░░░░░░░░░░░░░░░░░░│  │  │    │
        │   ├──┼──┬──┬──┬──┬──┬──┬──┬──┬──┬──┬──┬──┬──┼──┼──┤    │
        │ E │▓▓│▓▓│▓▓│▓▓│▓▓│▓▓│▓▓│▓▓│▓▓│▓▓│▓▓│▓▓│▓▓│▓▓│▓▓│  │    │
        │   └──┴──┴──┴──┴──┴──┴──┴──┴──┴──┴──┴──┴──┴──┴──┴──┘    │
        │                        │                                 │
        │            Wires to TANITA connector                     │
        │                        │                                 │
        │            ┌───────────┴───────────┐                     │
        │            │  ┌─┐ ┌─┐ ┌─┐ ┌─┐ ┌─┐ ┌─┐                   │
        │            │  │G│ │V│ │M│ │M│ │S│ │C│                   │
        │            │  │N│ │C│ │O│ │I│ │C│ │S│                   │
        │            │  │D│ │C│ │S│ │S│ │L│ │ │                   │
        │            │  └─┘ └─┘ │I│ │O│ │K│ └─┘                   │
        │            │          └─┘ └─┘ └─┘                        │
        │            └─────────────────────────────────────────────│
        │                                                          │
        └──────────────────────────────────────────────────────────┘

        ▓▓ = ESP32 pins
        Wire connections at specific pin positions
```

---

## Step-by-Step Wiring Instructions

### Step 1: Prepare the ESP32

```
┌─────────────────────────────────────────────────────────────┐
│                                                             │
│   1. If using a new ESP32, first test it:                   │
│      - Connect USB cable                                    │
│      - Upload blink sketch                                  │
│      - Verify LED blinks                                    │
│                                                             │
│   2. Note your ESP32's pin layout                           │
│      - Check if it's 30-pin or 38-pin variant               │
│      - Identify GPIO23, GPIO19, GPIO18, GPIO5, GND, 3V3     │
│                                                             │
└─────────────────────────────────────────────────────────────┘
```

### Step 2: Identify TANITA Cable Signals

```
┌─────────────────────────────────────────────────────────────┐
│                                                             │
│   USE A MULTIMETER TO IDENTIFY EACH WIRE!                   │
│                                                             │
│   With scale POWERED OFF:                                   │
│   ┌─────────────────────────────────────────────────────┐   │
│   │ 1. Set multimeter to continuity mode                │   │
│   │ 2. Find GND: Test each wire against battery (-)     │   │
│   │ 3. Find VCC: Test against battery (+) or capacitors │   │
│   └─────────────────────────────────────────────────────┘   │
│                                                             │
│   With scale POWERED ON (careful!):                         │
│   ┌─────────────────────────────────────────────────────┐   │
│   │ 1. Set multimeter to DC voltage mode                │   │
│   │ 2. Measure each wire against GND                    │   │
│   │ 3. VCC should show ~3.3V constant                   │   │
│   │ 4. Other wires may show varying voltages            │   │
│   └─────────────────────────────────────────────────────┘   │
│                                                             │
│   Best method - LOGIC ANALYZER:                             │
│   ┌─────────────────────────────────────────────────────┐   │
│   │ 1. Connect logic analyzer to all signal wires       │   │
│   │ 2. Power on scale and trigger a measurement         │   │
│   │ 3. SCLK = regular clock pattern                     │   │
│   │ 4. CS = goes LOW during each transaction            │   │
│   │ 5. MOSI = data bursts (commands from handset)       │   │
│   │ 6. MISO = data bursts (responses to handset)        │   │
│   └─────────────────────────────────────────────────────┘   │
│                                                             │
└─────────────────────────────────────────────────────────────┘
```

### Step 3: Make the Connections

```
┌─────────────────────────────────────────────────────────────┐
│                                                             │
│   IMPORTANT: Double-check all connections before powering!  │
│                                                             │
│   Connection Table:                                         │
│   ┌─────────────────┬──────────────┬───────────────────┐   │
│   │  TANITA Wire    │  ESP32 Pin   │  Wire Color*      │   │
│   ├─────────────────┼──────────────┼───────────────────┤   │
│   │  GND            │  GND         │  (verify yours)   │   │
│   │  VCC (3.3V)     │  3V3**       │  (verify yours)   │   │
│   │  MOSI           │  GPIO23      │  (verify yours)   │   │
│   │  MISO           │  GPIO19      │  (verify yours)   │   │
│   │  SCLK           │  GPIO18      │  (verify yours)   │   │
│   │  CS             │  GPIO5       │  (verify yours)   │   │
│   └─────────────────┴──────────────┴───────────────────┘   │
│                                                             │
│   * Wire colors vary - always verify with multimeter!       │
│   ** VCC connection optional if ESP32 is USB powered        │
│                                                             │
└─────────────────────────────────────────────────────────────┘
```

### Step 4: Power Options

```
┌─────────────────────────────────────────────────────────────┐
│                                                             │
│   OPTION A: USB Power (Recommended for testing)             │
│   ┌─────────────────────────────────────────────────────┐   │
│   │                                                     │   │
│   │   [TANITA]──GND──────────┬────[ESP32 GND]          │   │
│   │            MOSI──────────┼────[ESP32 GPIO23]       │   │
│   │            MISO──────────┼────[ESP32 GPIO19]       │   │
│   │            SCLK──────────┼────[ESP32 GPIO18]       │   │
│   │            CS────────────┼────[ESP32 GPIO5]        │   │
│   │            VCC           │                          │   │
│   │             │            │                          │   │
│   │           (not          [USB]                       │   │
│   │          connected)       │                         │   │
│   │                        [5V Power]                   │   │
│   │                                                     │   │
│   └─────────────────────────────────────────────────────┘   │
│                                                             │
│   OPTION B: TANITA Power (Final installation)               │
│   ┌─────────────────────────────────────────────────────┐   │
│   │                                                     │   │
│   │   [TANITA]──GND──────────────[ESP32 GND]           │   │
│   │            VCC (3.3V)────────[ESP32 3V3]           │   │
│   │            MOSI──────────────[ESP32 GPIO23]        │   │
│   │            MISO──────────────[ESP32 GPIO19]        │   │
│   │            SCLK──────────────[ESP32 GPIO18]        │   │
│   │            CS────────────────[ESP32 GPIO5]         │   │
│   │                                                     │   │
│   │   Note: TANITA must provide enough current!         │   │
│   │   ESP32 needs ~250mA average, peaks to 500mA        │   │
│   │                                                     │   │
│   └─────────────────────────────────────────────────────┘   │
│                                                             │
└─────────────────────────────────────────────────────────────┘
```

---

## Complete Wiring Schematic

```
                            ┌──────────────────────────────────┐
                            │         ESP32 DevKit             │
                            │                                  │
                            │    ┌────────────────────────┐    │
    ┌───────────┐           │    │                        │    │
    │  TANITA   │           │    │      ┌────────┐        │    │
    │  Handset  │           │    │      │ ESP32  │        │    │
    │           │           │    │      │ WROOM  │        │    │
    │   ┌───┐   │           │    │      └────────┘        │    │
    │   │MCU│   │           │    │                        │    │
    │   └─┬─┘   │           │    │  3V3  ●────────────────┼───►│ VCC (optional)
    │     │     │           │    │                        │    │
    │   ──┴──   │           │    │  GND  ●────────────────┼───►│ GND
    └─────┬─────┘           │    │                        │    │
          │                 │    │  G23  ●────────────────┼───►│ MOSI
          │                 │    │       (VSPI MOSI)      │    │
    ┌─────┴─────┐           │    │                        │    │
    │ 6-wire    │           │    │  G19  ●────────────────┼───►│ MISO
    │ cable     │           │    │       (VSPI MISO)      │    │
    │           │           │    │                        │    │
    │ VCC ──────┼───────────┼────┼──────────► (optional)  │    │
    │ GND ──────┼───────────┼────┼──► GND                 │    │
    │ MOSI ─────┼───────────┼────┼──► GPIO23              │    │
    │ MISO ─────┼───────────┼────┼──► GPIO19              │    │
    │ SCLK ─────┼───────────┼────┼──► GPIO18              │    │
    │ CS ───────┼───────────┼────┼──► GPIO5               │    │  G18  ●────────────────┼───►│ SCLK
    │           │           │    │       (VSPI CLK)       │    │
    └───────────┘           │    │                        │    │
                            │    │  G5   ●────────────────┼───►│ CS
                            │    │       (VSPI CS)        │    │
                            │    │                        │    │
                            │    │  G2   ● (onboard LED)  │    │
                            │    │                        │    │
                            │    │  USB ━━━━━━━━━━━━━━━━━ │    │
                            │    │    (for programming)   │    │
                            │    │                        │    │
                            │    └────────────────────────┘    │
                            │                                  │
                            └──────────────────────────────────┘
```

---

## Signal Verification Checklist

After wiring, verify each connection:

```
┌─────────────────────────────────────────────────────────────┐
│                     VERIFICATION CHECKLIST                  │
├─────────────────────────────────────────────────────────────┤
│                                                             │
│  □ GND connected: TANITA GND ─── ESP32 GND                  │
│    Test: Continuity between both GND points                 │
│                                                             │
│  □ MOSI connected: TANITA MOSI ─── ESP32 GPIO23             │
│    Test: With logic analyzer, see commands from handset     │
│                                                             │
│  □ MISO connected: TANITA MISO ─── ESP32 GPIO19             │
│    Test: ESP32 can send responses to handset                │
│                                                             │
│  □ SCLK connected: TANITA SCLK ─── ESP32 GPIO18             │
│    Test: See clock signal on logic analyzer                 │
│                                                             │
│  □ CS connected: TANITA CS ─── ESP32 GPIO5                  │
│    Test: Goes LOW during SPI transactions                   │
│                                                             │
│  □ Power: Either USB or TANITA VCC (not both!)              │
│    Test: ESP32 powers on, LED blinks                        │
│                                                             │
│  □ No shorts between adjacent wires                         │
│    Test: No continuity between signal wires                 │
│                                                             │
└─────────────────────────────────────────────────────────────┘
```

---

## Troubleshooting Wiring Issues

### Problem: No SPI Data Received

```
┌─────────────────────────────────────────────────────────────┐
│  Possible Causes:                                           │
│                                                             │
│  1. MOSI/MISO swapped                                       │
│     → Swap GPIO23 and GPIO19 connections                    │
│                                                             │
│  2. CS not connected or wrong pin                           │
│     → Verify CS goes to GPIO5                               │
│     → Check CS goes LOW during transactions                 │
│                                                             │
│  3. GND not connected                                       │
│     → Verify common ground between TANITA and ESP32         │
│                                                             │
│  4. SCLK not connected                                      │
│     → Verify clock signal reaches GPIO18                    │
│                                                             │
└─────────────────────────────────────────────────────────────┘
```

### Problem: Garbled Data

```
┌─────────────────────────────────────────────────────────────┐
│  Possible Causes:                                           │
│                                                             │
│  1. Wrong SPI mode                                          │
│     → Try different modes in code (0, 1, 2, 3)              │
│                                                             │
│  2. Signal integrity issues                                 │
│     → Use shorter wires                                     │
│     → Add 10K pull-up on CS line                            │
│                                                             │
│  3. Voltage level mismatch                                  │
│     → Verify TANITA uses 3.3V (not 5V)                      │
│                                                             │
└─────────────────────────────────────────────────────────────┘
```

### Problem: Scale Shows Error

```
┌─────────────────────────────────────────────────────────────┐
│  Possible Causes:                                           │
│                                                             │
│  1. ESP32 not responding fast enough                        │
│     → Check serial output for received commands             │
│     → Verify responses are being sent                       │
│                                                             │
│  2. Wrong response data                                     │
│     → Check protocol implementation                         │
│     → Verify checksum calculations                          │
│                                                             │
│  3. MISO not connected properly                             │
│     → ESP32 can receive but can't respond                   │
│                                                             │
└─────────────────────────────────────────────────────────────┘
```

---

## Physical Installation Notes

### Prototype Setup (for testing)

```
    ┌────────────────────────────────────────────────────┐
    │                                                    │
    │   ┌─────────┐        Dupont         ┌─────────┐   │
    │   │ TANITA  │◄─────  Wires  ───────►│ ESP32   │   │
    │   │ Cable   │        (loose)        │ on      │   │
    │   │Connector│                       │Breadboard   │
    │   └─────────┘                       └─────────┘   │
    │                                          │        │
    │                                        [USB]      │
    │                                          │        │
    │                                    [Computer]     │
    │                                                    │
    └────────────────────────────────────────────────────┘
```

### Final Installation (inside scale)

```
    ┌────────────────────────────────────────────────────┐
    │                     TANITA Scale Housing           │
    │                                                    │
    │   ┌─────────────────────────────────────────────┐ │
    │   │                                             │ │
    │   │   Original SD PCB location                  │ │
    │   │   ┌─────────────────────────────┐           │ │
    │   │   │                             │           │ │
    │   │   │   ESP32 Mini/Compact board  │           │ │
    │   │   │   (e.g., ESP32-C3 Mini)     │           │ │
    │   │   │                             │           │ │
    │   │   │   Soldered connections      │           │ │
    │   │   │   or custom PCB adapter     │           │ │
    │   │   │                             │           │ │
    │   │   └─────────────────────────────┘           │ │
    │   │                                             │ │
    │   └─────────────────────────────────────────────┘ │
    │                                                    │
    └────────────────────────────────────────────────────┘

    Note: For final installation, consider:
    - ESP32-C3 Mini for smaller footprint
    - Custom PCB adapter matching original connector
    - Proper wire strain relief
    - Insulation from other components
```

---

## Quick Reference Card

```
╔═══════════════════════════════════════════════════════════════╗
║           TANITA WiFi Retrofit - Quick Wiring Reference       ║
╠═══════════════════════════════════════════════════════════════╣
║                                                               ║
║   TANITA Signal    ──────────►    ESP32 GPIO                  ║
║   ───────────────────────────────────────────                 ║
║   GND              ──────────►    GND                         ║
║   VCC (3.3V)       ──────────►    3V3 (optional)              ║
║   MOSI (to ESP)    ──────────►    GPIO23                      ║
║   MISO (from ESP)  ◄──────────    GPIO19                      ║
║   SCLK (clock)     ──────────►    GPIO18                      ║
║   CS (chip sel)    ──────────►    GPIO5                       ║
║                                                               ║
║   ⚠️  Always verify pinout with multimeter first!             ║
║   ⚠️  TANITA uses 3.3V logic - do NOT use 5V!                 ║
║                                                               ║
╚═══════════════════════════════════════════════════════════════╝
```

---

## Next Steps

After wiring is complete:

1. Upload the `tanita_spi_capture` sketch
2. Open Serial Monitor at 115200 baud
3. Power on the TANITA scale
4. You should see SPI transaction logs
5. If you see recognizable data (commands, file paths), wiring is correct!
6. Then proceed to the full `tanita_wifi` firmware

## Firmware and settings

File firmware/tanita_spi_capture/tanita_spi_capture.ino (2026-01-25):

/*
 * TANITA SPI Protocol Capture/Debug Tool
 *
 * Simple sketch for capturing and analyzing the SPI protocol
 * without WiFi functionality. Use this first to verify your
 * wiring and understand the communication.
 *
 * Hardware connections:
 *   ESP32 GPIO23 (MOSI) <- Handset MOSI
 *   ESP32 GPIO19 (MISO) -> Handset MISO
 *   ESP32 GPIO18 (SCLK) <- Handset SCLK
 *   ESP32 GPIO5  (CS)   <- Handset CS
 *   ESP32 3.3V          <- Handset VCC
 *   ESP32 GND           <- Handset GND
 */

#include "driver/spi_slave.h"

// Pin definitions
#define PIN_SPI_MOSI      23
#define PIN_SPI_MISO      19
#define PIN_SPI_SCLK      18
#define PIN_SPI_CS        5
#define PIN_LED           2

#define BUFFER_SIZE       128

// DMA-capable aligned buffers
WORD_ALIGNED_ATTR uint8_t rxBuffer[BUFFER_SIZE];
WORD_ALIGNED_ATTR uint8_t txBuffer[BUFFER_SIZE];

// Transaction tracking
volatile bool transactionDone = false;
volatile size_t rxLen = 0;

// Protocol state
enum State { IDLE, HANDSHAKE, FILE_OP };
State currentState = IDLE;

// Known file contents
const char* SYSTEM_FILE = "SD,TANITA,GRAPHV1\r\nDo not delete, modify, nor remove this system file by yourself!\r\n";
const char* PROFILE_FILE = "{0,16,~1,2,~3,4,MO,\"BC-601\",DB,\"01/01/1990\",Bt,0,GE,1,Hm,175.0,AL,2,CS,00\r\n";

String currentFile = "";
uint32_t fileOffset = 0;
uint32_t fileSize = 0;

// Data capture
String capturedData = "";

// ============================================================================
// Checksum
// ============================================================================

uint8_t calcChecksum(const uint8_t* data, size_t len) {
    uint8_t sum = 0;
    for (size_t i = 0; i < len; i++) {
        sum += data[i];
    }
    return ~sum;
}

// ============================================================================
// Response Builders
// ============================================================================

size_t buildResponse(uint8_t* tx, const uint8_t* pattern, size_t len) {
    memcpy(tx, pattern, len);
    return len;
}

size_t statusResponse(uint8_t cmd, uint8_t* tx) {
    tx[0] = 0x04;
    tx[1] = cmd | 0x80;
    tx[2] = (cmd == 0x11) ? 0x01 : 0x00;
    tx[3] = calcChecksum(tx, 3);
    return 4;
}

size_t fileInitResponse(uint8_t* tx) {
    tx[0] = 0x04;
    tx[1] = 0x94;
    tx[2] = 0x00;
    tx[3] = calcChecksum(tx, 3);
    return 4;
}

size_t fileInfoResponse(uint32_t size, uint8_t* tx) {
    tx[0] = 0x0D;
    tx[1] = 0xA1;
    tx[2] = 0x00; tx[3] = 0x00;
    tx[4] = 0x00; tx[5] = 0x00; tx[6] = 0x00; tx[7] = 0x00;
    tx[8] = size & 0xFF;
    tx[9] = (size >> 8) & 0xFF;
    tx[10] = (size >> 16) & 0xFF;
    tx[11] = (size >> 24) & 0xFF;
    tx[12] = calcChecksum(tx, 12);
    return 13;
}

size_t dataChunkResponse(const char* content, uint32_t contentLen, uint32_t offset, uint32_t reqSize, uint8_t* tx) {
    uint32_t remaining = contentLen - offset;
    uint32_t chunkSize = (remaining < reqSize) ? remaining : reqSize;
    uint8_t frameLen = 8 + chunkSize;

    uint32_t newOffset = offset + chunkSize;

    tx[0] = frameLen;
    tx[1] = 0xA3;
    tx[2] = 0x00; tx[3] = 0x00;
    tx[4] = newOffset & 0xFF;
    tx[5] = (newOffset >> 8) & 0xFF;
    tx[6] = (newOffset >> 16) & 0xFF;
    tx[7] = (newOffset >> 24) & 0xFF;

    for (uint32_t i = 0; i < chunkSize; i++) {
        tx[8 + i] = content[offset + i];
    }

    tx[frameLen] = calcChecksum(tx, frameLen);
    return frameLen + 1;
}

size_t endReadResponse(uint32_t offset, uint8_t* tx) {
    tx[0] = 0x09;
    tx[1] = 0xA2;
    tx[2] = 0x00; tx[3] = 0x00;
    tx[4] = offset & 0xFF;
    tx[5] = (offset >> 8) & 0xFF;
    tx[6] = (offset >> 16) & 0xFF;
    tx[7] = (offset >> 24) & 0xFF;
    tx[8] = calcChecksum(tx, 8);
    return 9;
}

size_t allocateResponse(uint32_t addr, uint8_t* tx) {
    tx[0] = 0x09;
    tx[1] = 0xA7;
    tx[2] = 0x00; tx[3] = 0x00;
    tx[4] = addr & 0xFF;
    tx[5] = (addr >> 8) & 0xFF;
    tx[6] = (addr >> 16) & 0xFF;
    tx[7] = (addr >> 24) & 0xFF;
    tx[8] = calcChecksum(tx, 8);
    return 9;
}

size_t writeAckResponse(uint8_t* tx) {
    tx[0] = 0x04;
    tx[1] = 0xC1;
    tx[2] = 0x00;
    tx[3] = 0x3A;
    return 4;
}

size_t writeChunkAckResponse(uint32_t nextAddr, uint8_t* tx) {
    tx[0] = 0x09;
    tx[1] = 0xA4;
    tx[2] = 0x00; tx[3] = 0x00;
    tx[4] = nextAddr & 0xFF;
    tx[5] = (nextAddr >> 8) & 0xFF;
    tx[6] = (nextAddr >> 16) & 0xFF;
    tx[7] = (nextAddr >> 24) & 0xFF;
    tx[8] = calcChecksum(tx, 8);
    return 9;
}

// ============================================================================
// Helper Functions
// ============================================================================

void printHex(const uint8_t* data, size_t len, const char* prefix) {
    Serial.print(prefix);
    for (size_t i = 0; i < len && i < 64; i++) {
        Serial.printf("%02X ", data[i]);
    }
    if (len > 64) Serial.print("...");
    Serial.println();
}

String extractPath(const uint8_t* data, size_t len) {
    String path = "";
    for (size_t i = 2; i < len - 1; i++) {
        if (data[i] >= 0x20 && data[i] <= 0x7E) {
            path += (char)data[i];
        } else {
            break;
        }
    }
    return path;
}

void extractWriteData(const uint8_t* data, size_t len) {
    for (size_t i = 2; i < len - 1; i++) {
        char c = data[i];
        if (c >= 0x20 && c <= 0x7E) {
            capturedData += c;
        } else if (c == 0x0D || c == 0x0A) {
            capturedData += c;
        }
    }
}

const char* getFileContent(const String& path) {
    if (path.indexOf("SYSTEM.TXT") >= 0) return SYSTEM_FILE;
    if (path.indexOf("PROF") >= 0) return PROFILE_FILE;
    return "";
}

// ============================================================================
// Protocol Handler
// ============================================================================

uint32_t writeAddr = 0;
uint32_t bytesWritten = 0;

size_t handleCommand(const uint8_t* rx, size_t len, uint8_t* tx) {
    if (len < 2) return 0;

    uint8_t frameLen = rx[0];
    uint8_t cmd = rx[1];

    printHex(rx, len, ">> RX: ");

    size_t respLen = 0;

    switch (cmd) {
        case 0x11:
        case 0x12:
        case 0x13:
            respLen = statusResponse(cmd, tx);
            Serial.println("   [STATUS]");
            break;

        case 0x14:
            respLen = fileInitResponse(tx);
            Serial.println("   [FILE_INIT]");
            break;

        case 0x21: // Read file path
            currentFile = extractPath(rx, len);
            fileOffset = 0;
            {
                const char* content = getFileContent(currentFile);
                fileSize = strlen(content);
            }
            Serial.printf("   [READ_FILE] %s (size=%d)\n", currentFile.c_str(), fileSize);
            respLen = fileInfoResponse(fileSize, tx);
            break;

        case 0x22: // End transfer
            respLen = endReadResponse(fileOffset, tx);
            Serial.println("   [END_TRANSFER]");
            if (capturedData.length() > 0) {
                Serial.println("\n========== CAPTURED DATA ==========");
                Serial.println(capturedData);
                Serial.println("====================================\n");
                capturedData = "";
            }
            break;

        case 0x23: // Request chunk
            {
                uint8_t chunkSize = rx[2];
                const char* content = getFileContent(currentFile);
                respLen = dataChunkResponse(content, fileSize, fileOffset, chunkSize, tx);
                fileOffset += chunkSize;
                if (fileOffset > fileSize) fileOffset = fileSize;
                Serial.printf("   [READ_CHUNK] size=%d, offset now=%d\n", chunkSize, fileOffset);
            }
            break;

        case 0x24: // Write chunk
            extractWriteData(rx, len);
            bytesWritten += (len - 3); // minus header and checksum
            writeAddr += 0x20;
            respLen = writeChunkAckResponse(writeAddr, tx);
            Serial.printf("   [WRITE_CHUNK] %d bytes, addr=0x%04X\n", len - 3, writeAddr);
            break;

        case 0x27: // Allocate
            writeAddr = rx[2] | (rx[3] << 8);
            bytesWritten = 0;
            respLen = allocateResponse(writeAddr, tx);
            Serial.printf("   [ALLOCATE] addr=0x%04X\n", writeAddr);
            break;

        case 0x41: // Write file path
            currentFile = extractPath(rx, len);
            {
                uint8_t mode = rx[len - 2];
                if (mode == 0x01) {
                    capturedData = "";
                    Serial.printf("   [WRITE_BEGIN] %s\n", currentFile.c_str());
                } else if (mode == 0x03) {
                    Serial.printf("   [WRITE_FINALIZE] %s\n", currentFile.c_str());
                }
            }
            respLen = writeAckResponse(tx);
            break;

        default:
            Serial.printf("   [UNKNOWN CMD 0x%02X]\n", cmd);
            break;
    }

    if (respLen > 0) {
        printHex(tx, respLen, "<< TX: ");
    }

    return respLen;
}

// ============================================================================
// SPI Callback
// ============================================================================

void IRAM_ATTR spiPostTrans(spi_slave_transaction_t* trans) {
    rxLen = trans->trans_len / 8;
    transactionDone = true;
}

// ============================================================================
// Setup
// ============================================================================

void setup() {
    Serial.begin(115200);
    delay(1000);

    Serial.println("\n================================");
    Serial.println("TANITA SPI Protocol Capture v1.0");
    Serial.println("================================\n");

    pinMode(PIN_LED, OUTPUT);

    // SPI slave config
    spi_bus_config_t buscfg = {
        .mosi_io_num = PIN_SPI_MOSI,
        .miso_io_num = PIN_SPI_MISO,
        .sclk_io_num = PIN_SPI_SCLK,
        .quadwp_io_num = -1,
        .quadhd_io_num = -1,
        .max_transfer_sz = BUFFER_SIZE,
    };

    spi_slave_interface_config_t slvcfg = {
        .spics_io_num = PIN_SPI_CS,
        .flags = 0,
        .queue_size = 1,
        .mode = 0,
        .post_setup_cb = nullptr,
        .post_trans_cb = spiPostTrans,
    };

    esp_err_t ret = spi_slave_initialize(HSPI_HOST, &buscfg, &slvcfg, SPI_DMA_CH_AUTO);
    if (ret != ESP_OK) {
        Serial.printf("SPI init failed: %d\n", ret);
        while (1) delay(1000);
    }

    Serial.println("SPI slave initialized. Waiting for data...\n");
    memset(txBuffer, 0, BUFFER_SIZE);
}

// ============================================================================
// Loop
// ============================================================================

void loop() {
    spi_slave_transaction_t trans;
    memset(&trans, 0, sizeof(trans));
    trans.length = BUFFER_SIZE * 8;
    trans.rx_buffer = rxBuffer;
    trans.tx_buffer = txBuffer;

    transactionDone = false;
    esp_err_t ret = spi_slave_queue_trans(HSPI_HOST, &trans, portMAX_DELAY);
    if (ret != ESP_OK) {
        delay(1);
        return;
    }

    spi_slave_transaction_t* rtrans;
    ret = spi_slave_get_trans_result(HSPI_HOST, &rtrans, portMAX_DELAY);
    if (ret != ESP_OK) {
        return;
    }

    if (rxLen > 0) {
        digitalWrite(PIN_LED, HIGH);

        // Process and prepare response for next transaction
        size_t respLen = handleCommand(rxBuffer, rxLen, txBuffer);

        // Pad remaining buffer with zeros
        for (size_t i = respLen; i < BUFFER_SIZE; i++) {
            txBuffer[i] = 0x00;
        }

        digitalWrite(PIN_LED, LOW);
    }
}

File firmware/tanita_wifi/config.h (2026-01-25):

#ifndef CONFIG_H
#define CONFIG_H

// ============================================================================
// WiFi Configuration
// ============================================================================
#define WIFI_SSID         "YOUR_WIFI_SSID"
#define WIFI_PASSWORD     "YOUR_WIFI_PASSWORD"

// ============================================================================
// HTTPS Endpoint Configuration
// ============================================================================
#define API_ENDPOINT      "https://your-server.com/api/weight"
#define API_KEY           "your-api-key-here"

// ============================================================================
// ESP32 SPI Slave Pin Configuration
// ============================================================================
// These pins connect to the handset connector (originally going to SD PCB)
// Adjust based on your wiring

#define PIN_SPI_MOSI      23    // Master Out Slave In (data from handset)
#define PIN_SPI_MISO      19    // Master In Slave Out (data to handset)
#define PIN_SPI_SCLK      18    // SPI Clock (from handset)
#define PIN_SPI_CS        5     // Chip Select (directly from handset, directly active low)

// ============================================================================
// LED Status Indicator (optional)
// ============================================================================
#define PIN_LED_STATUS    2     // Built-in LED on most ESP32 dev boards

// ============================================================================
// Debug Configuration
// ============================================================================
#define DEBUG_SERIAL      1     // Enable serial debug output
#define DEBUG_BAUD_RATE   115200

// ============================================================================
// Protocol Configuration
// ============================================================================
#define SPI_BUFFER_SIZE   256   // Max SPI transaction buffer size
#define DATA_BUFFER_SIZE  1024  // Buffer for measurement data accumulation

// ============================================================================
// Profile Configuration (simulated data for handset reads)
// ============================================================================
// This is the system file content the handset expects
#define SYSTEM_FILE_CONTENT "SD,TANITA,GRAPHV1\r\nDo not delete, modify, nor remove this system file by yourself!\r\n"

// Default profile (will be returned when handset reads PROF1.CSV)
// You can customize this based on your setup
#define DEFAULT_PROFILE "{0,16,~1,2,~3,4,MO,\"BC-601\",DB,\"01/01/1990\",Bt,0,GE,1,Hm,175.0,AL,2,CS,00\r\n"

// ============================================================================
// Timing Configuration
// ============================================================================
#define WIFI_CONNECT_TIMEOUT_MS   10000
#define HTTP_TIMEOUT_MS           5000

#endif // CONFIG_H

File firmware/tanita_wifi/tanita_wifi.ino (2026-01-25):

/*
 * TANITA WiFi Retrofit - ESP32 Firmware
 * Version: 1.1
 *
 * Replaces the SD Card PCB in TANITA BC-601/603/613 body scales
 * to send weight/body composition data via WiFi instead of SD card.
 *
 * This ESP32 acts as an SPI slave, responding to commands from the
 * handset using the proprietary TANITA protocol.
 *
 * Hardware connections:
 *   ESP32 GPIO23 (MOSI) <- Handset MOSI (data from handset)
 *   ESP32 GPIO19 (MISO) -> Handset MISO (data to handset)
 *   ESP32 GPIO18 (SCLK) <- Handset SCLK (clock from handset)
 *   ESP32 GPIO5  (CS)   <- Handset CS   (active low)
 *   ESP32 3.3V          <- Handset VCC
 *   ESP32 GND           <- Handset GND
 *
 * Protocol Analysis:
 *   Frame format: [length] [command] [payload...] [checksum]
 *   Checksum: ~(sum of all bytes except checksum) & 0xFF
 *   Response commands: request_cmd | 0x80
 */

#include <WiFi.h>
#include <HTTPClient.h>
#include <WiFiClientSecure.h>
#include "driver/spi_slave.h"
#include "config.h"

// ============================================================================
// Protocol Constants
// ============================================================================

// Command bytes (second byte of frame from handset)
#define CMD_STATUS_1        0x12
#define CMD_STATUS_2        0x13
#define CMD_STATUS_3        0x11
#define CMD_FILE_INIT       0x14
#define CMD_FILE_PATH       0x21
#define CMD_END_TRANSFER    0x22
#define CMD_DATA_CHUNK      0x23
#define CMD_WRITE_CHUNK     0x24
#define CMD_ALLOCATE        0x27
#define CMD_WRITE_PATH      0x41

// Response modifier
#define RESP_FLAG           0x80

// Virtual file paths
#define PATH_SYSTEM         "TANITA/GRAPHV1/SYSTEM/SYSTEM.TXT"
#define PATH_PROFILE_1      "TANITA/GRAPHV1/SYSTEM/PROF1.CSV"
#define PATH_DATA_1         "TANITA/GRAPHV1/DATA/DATA1.CSV"

// ============================================================================
// State Machine
// ============================================================================

enum ProtocolState {
    STATE_IDLE,
    STATE_HANDSHAKE,
    STATE_FILE_INIT,
    STATE_FILE_OPEN,
    STATE_READING,
    STATE_WRITING,
    STATE_WRITE_DATA,
    STATE_END
};

// ============================================================================
// Global Variables
// ============================================================================

// SPI buffers (must be DMA-capable, word-aligned)
WORD_ALIGNED_ATTR uint8_t spiRxBuffer[SPI_BUFFER_SIZE];
WORD_ALIGNED_ATTR uint8_t spiTxBuffer[SPI_BUFFER_SIZE];

// Protocol state
volatile ProtocolState currentState = STATE_IDLE;
volatile bool transactionComplete = false;
volatile size_t lastTransactionLen = 0;

// File simulation
String currentFilePath = "";
String currentFileContent = "";
uint32_t currentFileSize = 0;
uint32_t currentFileOffset = 0;
uint32_t writeAddress = 0;
uint32_t writeBaseAddress = 0;
uint8_t writeMode = 0;  // 0=none, 1=begin, 3=finalize

// Write chunk tracking
#define CHUNK_SIZE 32
uint32_t bytesWritten = 0;

// Measurement data accumulator
String measurementData = "";
bool measurementReceived = false;
bool writeInProgress = false;

// WiFi status
bool wifiConnected = false;

// ============================================================================
// Checksum Calculation
// ============================================================================

uint8_t calculateChecksum(const uint8_t* data, size_t len) {
    uint8_t sum = 0;
    for (size_t i = 0; i < len; i++) {
        sum += data[i];
    }
    return ~sum;
}

bool validateChecksum(const uint8_t* data, size_t len) {
    if (len < 2) return false;
    uint8_t expected = calculateChecksum(data, len - 1);
    return (data[len - 1] == expected);
}

// ============================================================================
// SPI Slave Callbacks
// ============================================================================

// Called after a transaction is complete
void IRAM_ATTR spiSlavePostTransCb(spi_slave_transaction_t *trans) {
    lastTransactionLen = trans->trans_len / 8;  // Convert bits to bytes
    transactionComplete = true;
}

// ============================================================================
// Response Builders
// ============================================================================

size_t buildStatusResponse(uint8_t cmd, uint8_t* buffer) {
    buffer[0] = 0x04;
    buffer[1] = cmd | RESP_FLAG;
    buffer[2] = 0x00;
    if (cmd == CMD_STATUS_3) {
        buffer[2] = 0x01;  // Ready flag
    }
    buffer[3] = calculateChecksum(buffer, 3);
    return 4;
}

size_t buildFileInitResponse(uint8_t* buffer) {
    buffer[0] = 0x04;
    buffer[1] = CMD_FILE_INIT | RESP_FLAG;  // 0x94
    buffer[2] = 0x00;
    buffer[3] = calculateChecksum(buffer, 3);
    return 4;
}

size_t buildFileInfoResponse(uint32_t fileSize, uint8_t* buffer) {
    buffer[0] = 0x0D;
    buffer[1] = 0xA1;
    buffer[2] = 0x00;
    buffer[3] = 0x00;
    buffer[4] = 0x00;
    buffer[5] = 0x00;
    buffer[6] = 0x00;
    buffer[7] = 0x00;
    // File size (little-endian)
    buffer[8] = fileSize & 0xFF;
    buffer[9] = (fileSize >> 8) & 0xFF;
    buffer[10] = (fileSize >> 16) & 0xFF;
    buffer[11] = (fileSize >> 24) & 0xFF;
    buffer[12] = calculateChecksum(buffer, 12);
    return 13;
}

size_t buildDataChunkResponse(const String& content, uint32_t offset, uint32_t chunkSize, uint8_t* buffer) {
    // Calculate actual bytes to send
    uint32_t remaining = content.length() - offset;
    uint32_t actualSize = min(chunkSize, remaining);

    // Frame length = 8 header bytes + data bytes
    uint8_t frameLen = 8 + actualSize;

    buffer[0] = frameLen;
    buffer[1] = 0xA3;
    buffer[2] = 0x00;
    buffer[3] = 0x00;
    // Offset (little-endian)
    uint32_t newOffset = offset + actualSize;
    buffer[4] = newOffset & 0xFF;
    buffer[5] = (newOffset >> 8) & 0xFF;
    buffer[6] = (newOffset >> 16) & 0xFF;
    buffer[7] = (newOffset >> 24) & 0xFF;

    // Copy data
    for (uint32_t i = 0; i < actualSize; i++) {
        buffer[8 + i] = content[offset + i];
    }

    buffer[frameLen] = calculateChecksum(buffer, frameLen);
    return frameLen + 1;
}

size_t buildEndReadResponse(uint32_t finalOffset, uint8_t* buffer) {
    buffer[0] = 0x09;
    buffer[1] = 0xA2;
    buffer[2] = 0x00;
    buffer[3] = 0x00;
    // Final offset (little-endian)
    buffer[4] = finalOffset & 0xFF;
    buffer[5] = (finalOffset >> 8) & 0xFF;
    buffer[6] = (finalOffset >> 16) & 0xFF;
    buffer[7] = (finalOffset >> 24) & 0xFF;
    buffer[8] = calculateChecksum(buffer, 8);
    return 9;
}

size_t buildAllocateResponse(uint32_t address, uint8_t* buffer) {
    buffer[0] = 0x09;
    buffer[1] = 0xA7;
    buffer[2] = 0x00;
    buffer[3] = 0x00;
    // Address (little-endian)
    buffer[4] = address & 0xFF;
    buffer[5] = (address >> 8) & 0xFF;
    buffer[6] = (address >> 16) & 0xFF;
    buffer[7] = (address >> 24) & 0xFF;
    buffer[8] = calculateChecksum(buffer, 8);
    return 9;
}
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

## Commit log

2026-01-25 Add ESP32 firmware and protocol documentation for TANITA WiFi retrofit
    - Complete protocol documentation (docs/PROTOCOL.md)
    - Pinout investigation guide (docs/PINOUT_INVESTIGATION.md)
    - ESP32 SPI capture/debug sketch (firmware/tanita_spi_capture/)
    - Full WiFi implementation with HTTPS POST (firmware/tanita_wifi/)
    - PlatformIO build configuration
    - Firmware README with setup instructions
    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
2026-06-04 Add passive SPI protocol grabber: ESP32-S3 sniffer, decoder, KiCad tap
    Adds a passive grabbing -> documentation pipeline, distinct from the
    existing SD-card emulator (tanita_spi_capture):
    - firmware/tanita_spi_sniffer: ESP32-S3 dual-SPI-slave passive bus tap.
    Both peripherals run as slaves on shared SCK+CS (miso disabled), so the
    tap is high-impedance and never drives the live bus. SPI2 listens MOSI,
    SPI3 listens MISO; one CS pulse yields a byte-aligned full-duplex pair
    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
    [tanita_sniffer.kicad_sch]
2026-06-04 Add breadboard wiring drawing (SVG) for the passive tap
    Fritzing-style physical layout: ESP32-S3 DevKitC, mini breadboard with the
    four 100R series resistors, and the CN1 handset connector, with color-coded
    jumpers matching the wiring table. Generated by hardware/gen_breadboard_svg.py
    (well-formed SVG, renders inline on GitHub). Referenced from hardware/README.md.
2026-06-14 Add detailed wiring guide with ASCII diagrams
    Includes:
    - ESP32 pinout diagrams (30-pin and 38-pin variants)
    - Complete wiring schematic with signal directions
    - Breadboard layout visualization
    - Step-by-step connection instructions
    - Signal verification checklist
    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
2026-06-14 Add comprehensive project plan with milestones and task backlog
    - Current status tracking (completed/in-progress/pending)
    - 4 milestones: Hardware, Protocol, WiFi, Production
    - Detailed task backlog with estimates and dependencies
    - Risk register and technical debt tracking
    - Timeline estimates (~1 week to MVP)
